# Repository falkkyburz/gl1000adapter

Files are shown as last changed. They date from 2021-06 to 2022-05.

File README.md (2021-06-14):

# Vector GL1000 Adapter

This is an adapter for the Vector GL1000 series of data loggers to adapt the D-SUB 25 connector to two 
D-SUB 9 standard CAN pinout connectors.

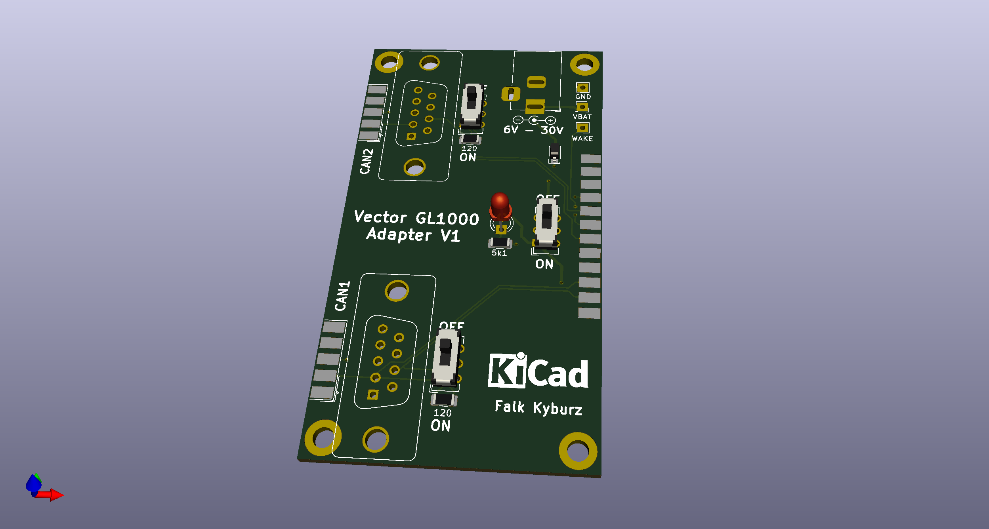
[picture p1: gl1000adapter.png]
gl1000adapter render


## BOM

I also included the interactive html BOM (gl1000adapter.html) 

| References | Value | Footprint | Quantity |
|---|---|---|---|
| R1 | 5k1 | 1206 | 1 |
| R2, R3 | 120 | 1206 | 2 |
| D1 | green | LED_3mm | 1 |
| D2 | SM400 | SOD-123 | 1 |
| SW1, SW2, SW3  | K3-2235D-K1 or similar | | 3 |
| J1 | DC005-T20 or similar | 5.5/2.1mm | 1 |
| J3 | DB25 female | | 1 |
| J2, J4 | DB9 female | | 2 |
| J5, J6 | DB9 male vertical | | 2 |

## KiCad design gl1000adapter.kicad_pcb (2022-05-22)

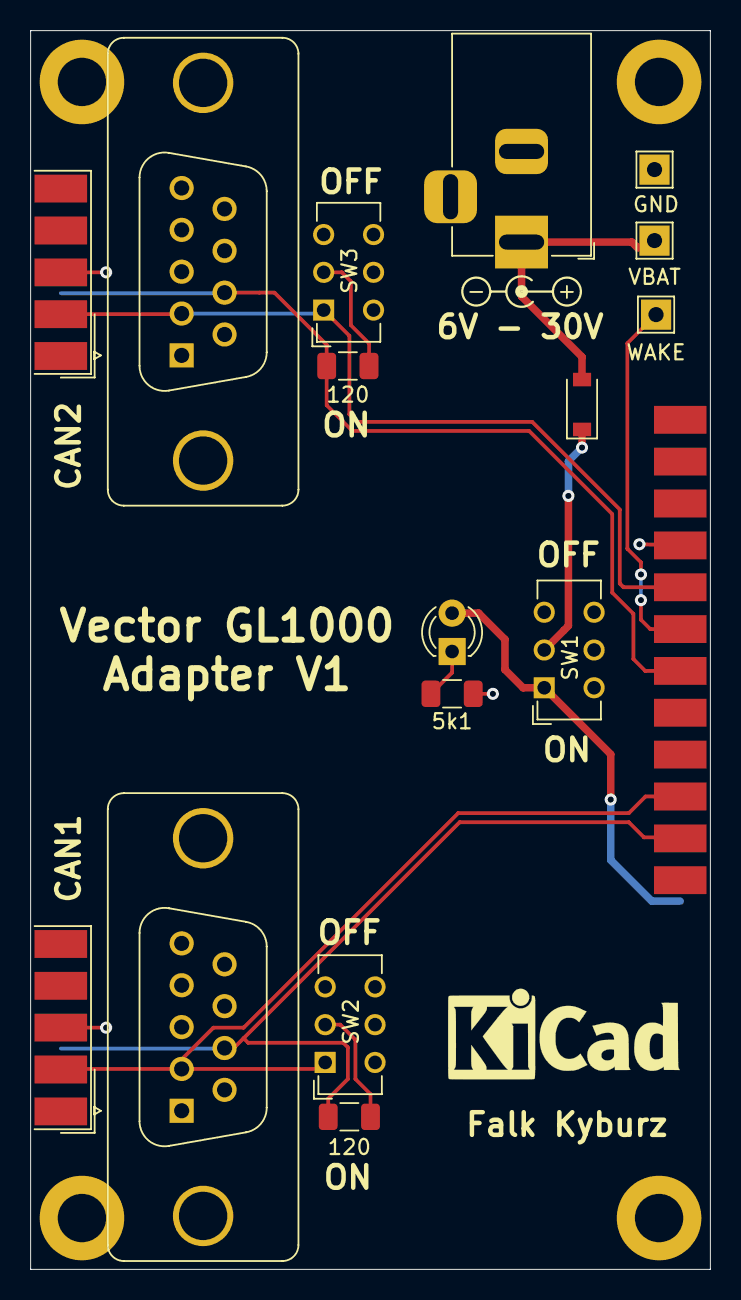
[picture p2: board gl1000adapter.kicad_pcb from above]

Board: 2 copper layers, 45.0 x 82.0 mm, 17 parts (1 on the bottom side), 12 nets.

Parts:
D1: LED 3mm green; LED_D3.0mm
D2: SM4007PL; D_SOD-123
J1: Barrel_Jack; BarrelJack_Horizontal
J2, J4: DS1033-09FUNSiSS; DSUB-9_Female_EdgeMount_P2.77mm
J3: DB25_Female; DSUB-25_Female_EdgeMount_P2.77mm
J5, J6: DS1034-09MUNSi44; DSUB-9_Male_Vertical_P2.77x2.84mm_MountingHoles
R1: 5k1; R_1206_3216Metric
R2, R3: 120; R_1206_3216Metric
SW1, SW2, SW3: K3-2235D-K1; SW_CuK_JS202011CQN_DPDT_Straight
TP1: WAKE; TestPoint_THTPad_2.0x2.0mm_Drill1.0mm
TP12: VBAT; TestPoint_THTPad_2.0x2.0mm_Drill1.0mm
TP13: GND; TestPoint_THTPad_2.0x2.0mm_Drill1.0mm

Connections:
/CAN1H: J2.7, J3.15, J5.7, R2.1
/CAN1L: J2.2, J3.16, J5.2, SW2.1
/CAN2H: J3.19, J4.7, J6.7, R3.1
/CAN2L: J3.21, J4.2, J6.2, SW3.1
/GND: J1.2, J2.3, J2.6, J3.4, J3.7, J3.22, J4.3, J4.6, J5.3, J5.6, J6.3, J6.6, R1.2, TP13.1
/VBAT: D2.2, J1.1, TP12.1
/VBAT1: D2.1, SW1.2
/VBAT2: D1.2, J3.1, SW1.1
/WAKE: J3.20, TP1.1
unnamed: D1.1, R1.1
unnamed: R2.2, SW2.2
unnamed: R3.2, SW3.2

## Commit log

2021-05-13 Added missing value for R1.
    [gl1000adapter.kicad_pcb, gl1000adapter.sch]
2021-06-14 Mayor modifications, added second pair of DB9s, added switchable termination resistors.
    [gl1000adapter.kicad_pcb, gl1000adapter.sch]
2022-05-22 Data as ordered.
    [gl1000adapter.kicad_pcb]
